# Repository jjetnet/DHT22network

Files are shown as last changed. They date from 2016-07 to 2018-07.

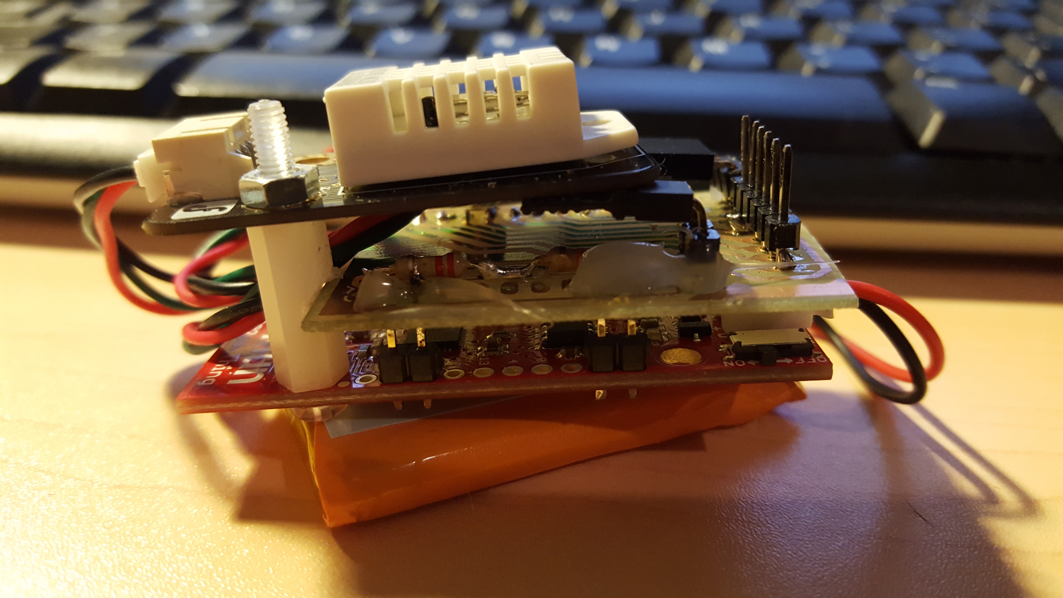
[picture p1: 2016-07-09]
example_sensor_module_assembled.jpg

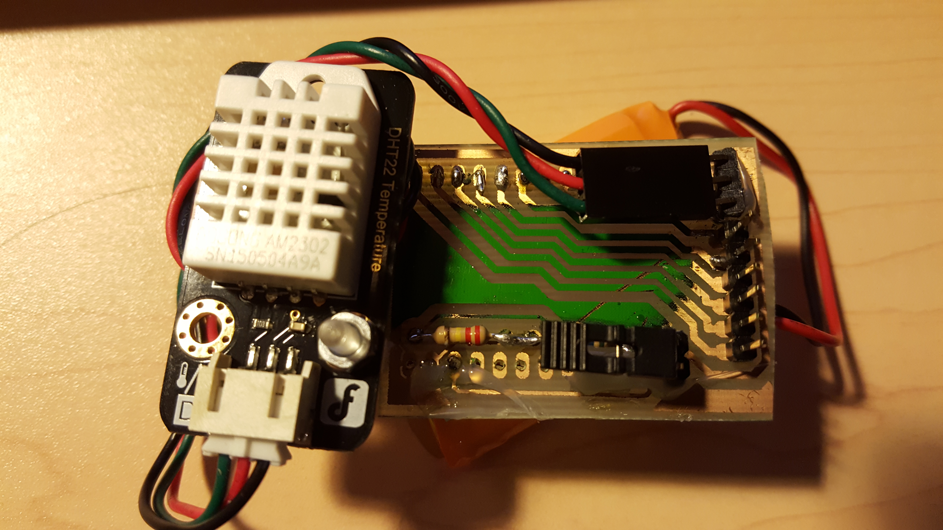
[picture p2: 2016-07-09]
sensor_module_PCB_top_view.jpg

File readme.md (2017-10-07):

# DHT22network
wifi dht22 network

Note: there are many similar, and probably better implementation of
similar concepts. My python coding in particular is far from optimal
or elegant. This implementation has mobile notifications, plots and water partial pressure
calculations which distinguishes it from others, but if you don't need
this look around for better implementations.

## Overview:

Arduino code, eagle files and python script for a wifi based array of
humidity and temperature sensors sending data back periodically to a
server. The server generates plots and tables of current data
displayed on a webpage - on the local server, and/or on a remote web
server through ftp. The sensors are meant for indoors reading, with
outside temperature read from publicly available data from the
Australian bureau of meteorology (data for australia only...).  The
number of sensors is not really limited (Although past a certain
number i'm sure bugs will emerge), and the server just adapts when a
new sensor comes online.

Each sensor can be battery operated for a number of months or even
years depending on refresh settings and battery - power consumption
between readings is minimal. The server can send notificatinos to
android and iphone phones using the free pushetta service/app (See
www.pushetta.com) when outside temperature goes above or below user
defined thresholds - useful to remember to close windows, curtains or
blinds.  Each sensor also reads its battery level, also displayed on
the webpage as battery voltage with a crude red/green color coding
depending on battery state.

For example of what the webpage looks like see
webpageexample.png. Data displayed includes temperature, relative
humidity and the water partial pressure - the latter is absolute
rather than relative, and is more informative if you want to control
the flow of humidity between two rooms or between outdoows and
indoors: if two rooms are at different temperatures but identical
relative humidity, there will still be a net flow of water vapour from
the space with the higher partial water pressure to the room with the
lower one. If you want to keep humidity down indoors in summer, this
is the quantity to watch to close/open windows, rather than the
relative humidity.

Each sensor is based on an esp8266 - specifically i used a sparkfun
esp8266 thing, which includes a convenient LiPo battery charger. Wifi
network and key, location name, and python server addess and port have
to be adjusted in the arduino code before uploading.

The server collecting data is a python script, which has to be run
with sufficient priviledges to write onto the web server's folder (eg
`/var/www/` ). All server data is defined in a separate configuration
script (tempTCPconfig.py). I run mine on a raspbery pi.

## Hardware

A minimal version can be assembled without PCB, using a ESP8266 thing the DHT22 sensor, and a jumper wire between XPD and DTR (which needs to be removed for programming). To add battery monitoring, two resistors straight onto the ESP8266 thing between Vin, Gnd and Analog in forming a ~1/5 voltage divider is enough. (220k between Vin and Analog in, 56k between gnd and Analog in) (see eagle schematic for details).

Alternatively, a PCB can be used to clean up the circuit: 

The current version of the pcb (eagle file) is awkward - components are on
the copper side, which makes for some difficult soldering for some
pins.

The two jpeg files show an example of an assembled sensor module using PCB,
outside its casing - as mentioned it is a tad awkward in this
implementation. There's some hot glue that was requried to stabilise
some of the copper wiring which had lifted off when accidentally
pushing on the module... The top view with sensor rotated shows the
two resistors that make up the voltage divider to bring the battery
voltage within the range of the ESP8266 1V ADC, as well as the jumper
that needs to be removed for programming (it connects XPD to DTR to
enable deep sleep - see [sparkfun's sleepmode tutorial](https://learn.sparkfun.com/tutorials/esp8266-thing-hookup-guide/example-sketch-goodnight-thing-sleep-mode). The
six open pins are a copy of the programming port of the esp8266 so
that the the module can still be programmed.  This particular example
uses a DHT22 module from df robotics, but a naked DHT22 can also be
used.

For the battery to last months rather than hours or days, the power LED has to be disconnected, see [sparkfun's sleepmode tutorial](https://learn.sparkfun.com/tutorials/esp8266-thing-hookup-guide/example-sketch-goodnight-thing-sleep-mode)

For this example, I used a LiPo 1000mAh LiPo battery, which is of similar size to the esp8266 thing module.

## Installation:
The python-based server requires a number of libraries,
some of which are not in the default python install for raspberry
pi (if you chose to run the server on a raspberry pi). In particular pushetta, matplotlib and a recent version of numpy
are requried, which you may have to install from source depending on
your distribution/package manager. I'm not sure which version is
required, but it runs with numpy 1.11.0, matplotlib 1.1.1rc2, pushetta
1.0.15.
Notifications require a free account with the pushetta service. For this, and how to install the pushetta python package, see [the puhsetta help page](http://pushetta.com/pushetta-docs).
Feel free to contact me (open an issue) if you have any trouble installing or running the server.

## Updates:
### 13/08/16
* increased stability: exception handling for ftp and pushetta. The python server seems very stable now.
* remover redundant, unused plot routine.

### 30/07/16
* fixed stability issues when remote ftp server or bureau of meteorology websites are not responsive.
* fixed plotting - no more error messages when insufficient data points, and limited long-term plot to last 30 days for readability

## Known issues:
* Arduino code:  If the server is down or a sensor module fails for any other reason to communicate with the server, it will keep trying continuously for ever - the battery will then run out rapidly.
* safety: ftp passwords are in clear text in the python configuration file, and  so is the wifi password in the arduino code. MAke sure to protect those files. TCP communications between sensor module and server are unencrypted.

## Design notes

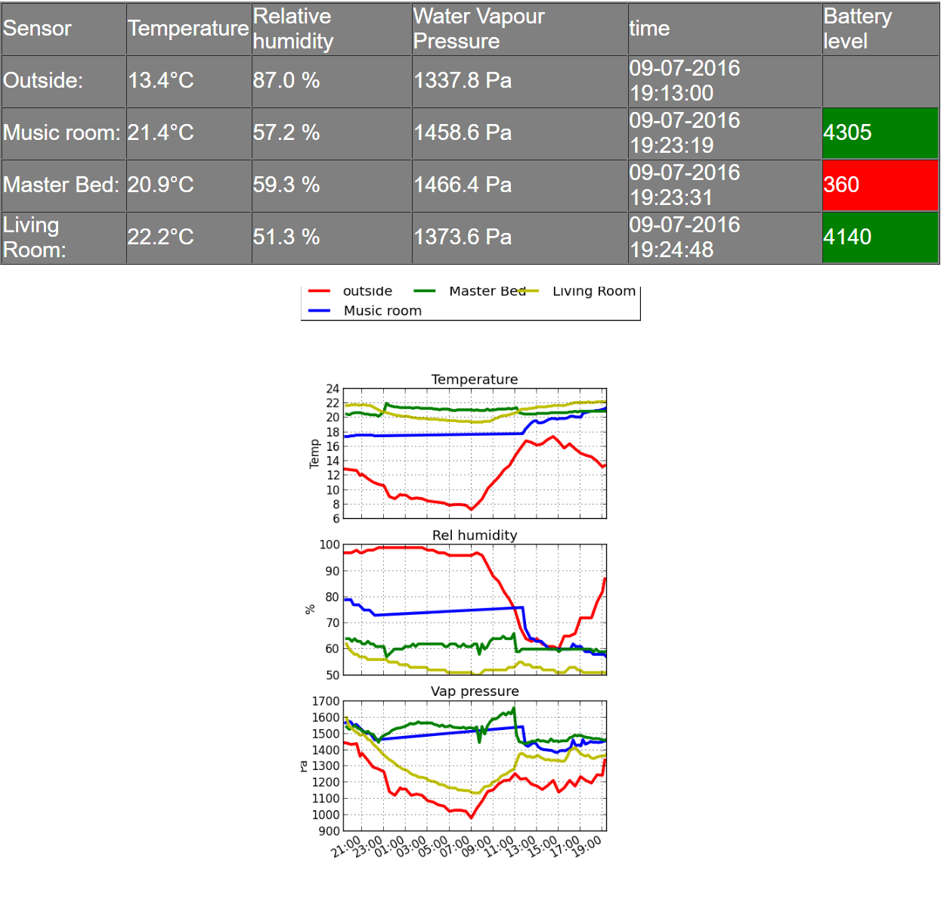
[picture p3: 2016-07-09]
webpageexample.png

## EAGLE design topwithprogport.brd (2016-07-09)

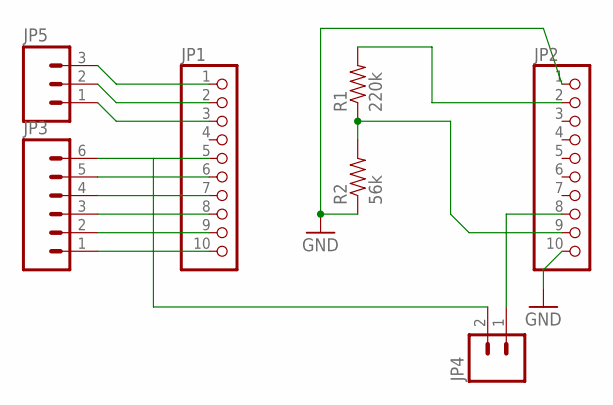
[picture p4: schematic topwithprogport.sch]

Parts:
JP1, JP2: PINHD-1X10; 1X10
JP3: M06LONGPADS; 1X06_LONGPADS
JP4: M02LOCK_LONGPADS; 1X02_LOCK_LONGPADS
JP5: M03LOCK_LONGPADS; 1X03_LOCK_LONGPADS
R1: 220k; AXIAL-0.4
R2: 56k; AXIAL-0.4

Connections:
GND: JP1.1, JP2.1, JP2.10, JP5.3, R2.P$1 (1)
unnamed: JP2.9, R1.P$1 (1), R2.P$2 (2)
unnamed: JP2.2, R1.P$2 (2)
unnamed: JP2.8, JP4.1
unnamed: JP1.5, JP3.6, JP4.2
unnamed: JP1.6, JP3.5
unnamed: JP1.7, JP3.4
unnamed: JP1.8, JP3.3
unnamed: JP1.9, JP3.2
unnamed: JP1.10, JP3.1
unnamed: JP1.2, JP5.2
unnamed: JP1.3, JP5.1

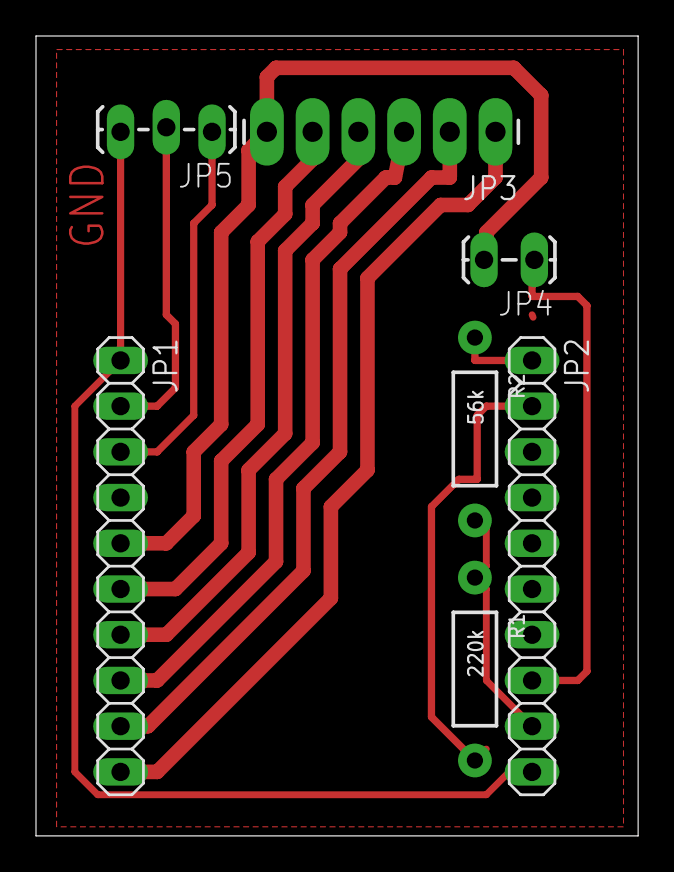
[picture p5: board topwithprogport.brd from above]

Board: 2 copper layers, 33.5 x 44.4 mm, 7 parts (0 on the bottom side), 12 nets.

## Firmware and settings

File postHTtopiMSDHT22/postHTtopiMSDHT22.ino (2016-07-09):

// Humidity and tmeperature sensor sending data to python server over wifi - based on phant post example on sparkfun
// Include the ESP8266 WiFi library. (Works a lot like the
// Arduino WiFi library.)
// REMOVE SLEEP JUMPER BEFORE UPLOADING
// apart from DHT: connect 56kOhm between ground and AD0 and 220kOhm between Vin and ground
// to measure battery voltage, mutiply AD read by 5 to get voltage
// I started from the post to phant example code of sparkfun - there are some remanents of it in here (but the code does something quite different now...)
// data is sent as a json string to the python server
// You will need to adapt WiFi definitions and server host IP/port below
#include <ESP8266WiFi.h>
#include <dht.h> //use dht

/************* uncomment this to read vdd - but useless for sparkfun thing as after regulator
extern "C" {
uint16 readvdd33(void);
}
*/

//////////////////////
// WiFi Definitions //
//////////////////////
const char WiFiSSID[] = "wifinetwork";
const char WiFiPSK[] = "yourwifipassword";
////// Each sensor needs to have a different sensor name
const char SensorID[]="Living room";

///////////////////////////////////
// Python server host definitons - adapt to your own  //
///////////////////////////////////
const char PiHost[] = "192.168.2.101";
const int PiPort = 8888;


/////////////////////
// Pin Definitions //
/////////////////////
const int LED_PIN = 5; // Thing's onboard, green LED
const int ANALOG_PIN = A0; // Analog pin (only one on ESP8266)


dht DHT;

#define DHT22_PIN 2

/////////////////
// Post Timing //
/////////////////
// Time to sleep (in minutes):
// can be updated remotely (to be implemented)
const int sleepTimeS = 15*60; //seconds (or minutes if modifying line for esp.deepsleep)

// string variables needed for posting to server
char postString[40]; // output string for client write
char charbuf[40];

void setup() 
{
  initHardware();
  connectWiFi();
  digitalWrite(LED_PIN, HIGH);
  
  while(postToPi() != 1){
    delay(200);
    }
  // deepSleep time is defined in microseconds. Multiply
  // seconds by 1e6 
  ESP.deepSleep(sleepTimeS * 1000000); //60*1000000);
}

void loop() 
{

}

void connectWiFi()
{
  byte ledStatus = LOW;

  // Set WiFi mode to station (as opposed to AP or AP_STA)
  WiFi.mode(WIFI_STA);

  // WiFI.begin([ssid], [passkey]) initiates a WiFI connection
  // to the stated [ssid], using the [passkey] as a WPA, WPA2,
  // or WEP passphrase.
  WiFi.begin(WiFiSSID, WiFiPSK);

  // Use the WiFi.status() function to check if the ESP8266
  // is connected to a WiFi network.
  while (WiFi.status() != WL_CONNECTED)
  {
    // Blink the LED
    digitalWrite(LED_PIN, ledStatus); // Write LED high/low
    ledStatus = (ledStatus == HIGH) ? LOW : HIGH;

    // Delays allow the ESP8266 to perform critical tasks
    // defined outside of the sketch. These tasks include
    // setting up, and maintaining, a WiFi connection.
    delay(200); // was 100 in original example
    // Potentially infinite loops are generally dangerous.
    // Add delays -- allowing the processor to perform other
    // tasks -- wherever possible.
  }
}

void initHardware()
{
  //Serial.begin(9600);
  pinMode(DIGITAL_PIN, INPUT_PULLUP);
  pinMode(LED_PIN, OUTPUT);
  digitalWrite(LED_PIN, LOW);
  // Don't need to set ANALOG_PIN as input, 
  // that's all it can be.
}

int postToPi()
{
  // LED turns on when we enter, it'll go off when we 
  // successfully post.
  
  digitalWrite(LED_PIN, HIGH);

  
   int chk = DHT.read22(DHT22_PIN);
   switch (chk)
  {
    case DHTLIB_OK:     
   {
       dtostrf(DHT.humidity,5,1,charbuf);
       strcpy(postString,"{\"H\": ");
       strcat(postString,charbuf );
       strcat(postString,", \"T\": ");
       dtostrf(DHT.temperature,5,1,charbuf);
       strcat(postString,charbuf );
       strcat(postString,", \"S\": \"");
       strcat(postString,SensorID);
       strcat(postString,"\", \"B\": " );  
       sprintf (charbuf, "%i", analogRead(A0)*5); // there's a /5 voltage divider
       strcat(postString,charbuf);
       strcat(postString,"}\n" );  
       break;
  }
    case DHTLIB_ERROR_CHECKSUM: 
      strcpy(postString,"{\"T\": -1,\"H\": -1, \"S\": \""); 
      strcat(postString,SensorID);
      strcat(postString,"\"}\n" );  

      break;
    case DHTLIB_ERROR_TIMEOUT: 
      strcpy(postString,"{\"T\": -2,\"H\": -2, \"S\": \""); 
      strcat(postString,SensorID);
      strcat(postString,"\"}\n" );  
      break;
    case DHTLIB_ERROR_CONNECT:
      strcpy(postString,"{\"T\": -3,\"H\": -3, \"S\": \""); 
      strcat(postString,SensorID);
      strcat(postString,"\"}\n" );  
      break;
    case DHTLIB_ERROR_ACK_L:
      strcpy(postString,"{\"T\": -4,\"H\": -4, \"S\": \""); 
      strcat(postString,SensorID);
      strcat(postString,"\"}\n" );  
        break;
    case DHTLIB_ERROR_ACK_H:
      strcpy(postString,"{\"T\": -5,\"H\": -5, \"S\": \""); 
      strcat(postString,SensorID);
      strcat(postString,"\"}\n" );  
      break;
    default: 
      strcpy(postString,"{\"T\": -6,\"H\": -6, \"S\": \""); 
      strcat(postString,SensorID);
      strcat(postString,"\"}\n" );  
      break;
  }
  // check if returns are valid, if they are NaN (not a number) then something went wrong!
    
  // Now connect to data.sparkfun.com, and post our data:
  WiFiClient client;
  
  if (!client.connect(PiHost, PiPort)) 
  {
    // If we fail to connect, return 0. double blink to show
    digitalWrite(LED_PIN,HIGH);
    delay(100);
    digitalWrite(LED_PIN,LOW);
    delay(100);
    digitalWrite(LED_PIN,HIGH);
    delay(100);
    digitalWrite(LED_PIN,LOW);
    delay(100);

    return 0;
  }
  // If we successfully connected, print our Phant post:
  client.print(postString);

  // Read all the lines of the reply from server and print them to Serial
  //while(client.available()){
    //String line = client.readStringUntil('\r');
    //Serial.print(line); // Trying to avoid using serial
  //}
  //delay(300); // so i can see LED
  // Before we exit, turn the LED off.
  digitalWrite(LED_PIN, LOW);

  return 1; // Return success
}

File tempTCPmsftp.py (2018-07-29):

# class for current climate data hteml generation/update, includines BOM data reading
# relative humidity to water vapour partial pressure conversion, and
# reading from multiple sparkfun thing wifi sensors

import matplotlib
matplotlib.use('Agg')
import requests
    
from ftplib import FTP 
import json,math
import serial
import matplotlib.pyplot as plt
import matplotlib.dates as md
import numpy as np
import gc
import socket
import threading
import sys
import matplotlib.cbook as cbook
from pushetta import Pushetta
# import network configuration etc
from tempTCPconfig import *

#import time
from time import asctime,localtime,time,sleep,strftime,strptime,mktime
import datetime
NaN=float('NaN')

dateconv = np.vectorize(datetime.datetime.fromtimestamp)
class TCPlistener:
    def __init__(self,port,errfilen):
        # initiate TCP listener on port port, log errors on file object errfilen, which must be open
        self.port=port
        self.s = socket.socket(socket.AF_INET, socket.SOCK_STREAM)
        self.s.setsockopt(socket.SOL_SOCKET, socket.SO_REUSEADDR, 1)
        self.errfilen=errfilen;
        #Bind socket to local host and port
        self.exitloop=False
        try:
            self.s.bind(('', port))
        except socket.error as msg:
            self.inflog('Bind failed. Error Code : ' + str(msg[0]) + ' Message ' + msg[1]);
            sys.exit()
            self.exitloop=True

        self.s.listen(5)
        self.TCPlistener()
        
    def _TCPlistener(self):
        # listens to TCP port and start new thread for each connection
        # call through TCPlistener to put this in non blocking thread
        while not self.exitloop:
            # print '.'
            conn, addr = self.s.accept()
            self.inflog('Connected with ' + addr[0] + ':' + str(addr[1]))
            t=threading.Thread(target=self.clientthread ,args=(conn,))
            t.start()
            t.join()

        self.s.close()
        sys.exit()


    def TCPlistener(self):
        threading.Thread(target=self._TCPlistener).start()
        
    def clientthread(self,conn):
    #infinite loop so that function do not terminate and thread do not end. probably not needed with curent exit condition
        while True:
            #Receiving from client
            
            data = conn.recv(1024)
            self.inflog('"'+data.strip()+'"')
            if(data!=''):
                try:
                    sensordata=json.loads(data)
                    self.it=sensordata["T"]
                    self.ih=sensordata["H"]
                    self.sensorID=sensordata["S"]
                    try:
                        self.battery=sensordata["B"]
                    except:
                        self.battery=-1

                    self.itimestamp=localtime(time())
                    self.gotnewdata=True
                    break
                except:
                    self.inflog('json error: "'+str(data)+'"')
                    data=False
                    break

#                conn.send('
            #reply = 'OK...' + data
            if not data: 
                break

            #conn.sendall(reply)

        #came out of loop
        conn.close()
	return 0
    
    def inflog(self,txt):
        txt=strftime('%d-%m-%Y %H:%M:%S')+': '+txt+'\n'
        self.errfilen.write(txt)
        self.errfilen.flush()
          

class climatehtmlfileTCP:
    def __init__(self,filepath,bomurl,fileradix,port,errfile,lowT,highT):
        self.filename=filepath+fileradix+'.html'
        self.bomurl=bomurl
        self.datalogfile=filepath+fileradix
        self.fileradix=fileradix
        self.filepath=filepath
        self.port=port
        self.errfile=errfile
        self.errfilen=open(errfile,'a',0) # error file in unbuffered
        self.TCPlistener=TCPlistener(port,self.errfilen)
        self.TCPlistener.gotnewdata=False
        self.sensidtable={}
        self.lastUpdate=time()-60 
        self.alertTempLow=lowT
        self.alertTempHigh=highT
        self.sentAlertHigh=False
        self.sentAlertLow=False
        self.inflog('climateHTMLfile class initiated')
        if(API_KEY):
            self.p=Pushetta(API_KEY)
            self.p.pushMessage(CHANNEL_NAME,"Service started")            
        else:
            self.p=False

    def inflog(self,txt):
        txt=strftime('%d-%m-%Y %H:%M:%S')+': '+txt+'\n'
        self.errfilen.write(txt)
        self.errfilen.flush()
            
    def waterPartialPressure(self,temperature,humidity):
        "Calculates watersaturatiopressure(temperature,humidity) temperautre (C), h (%)"
        # formula for water saturation vapor pressure from
        # http://www.vaisala.com/Vaisala%20Documents/Application%20notes/Humidity_Conversion_Formulas_B210973EN-F.pdf
        Tc = 647.096 
        Pc = 22064000
        C1 = -7.85951783
        C2 = 1.84408259
        C3 = -11.7866497
        C4 = 22.6807411
        C5 = -15.9618719
        C6 = 1.80122502
        t=1-(temperature+273.15)/Tc
        pw=humidity/100*Pc*math.exp(Tc/(temperature+273.15)*(C1*t+C2*math.pow(t,1.5)+C3*math.pow(t,3)+C4*math.pow(t,3.5)+C5*math.pow(t,4)+C6*math.pow(t,7.5)))
        #print pw
        return pw

    def getBomData(self):
        "get BOM observations"
        try:
            response=requests.get(self.bomurl)
            self.bomdata=json.loads(response.content)
            self.ot=float(self.bomdata["observations"]["data"][0]["air_temp"])
            self.oh=float(self.bomdata["observations"]["data"][0]["rel_hum"])
            self.bomdatatime=self.bomdata["observations"]["data"][0]["local_date_time"]
            bomd=self.bomdata["observations"]["data"][0]["local_date_time_full"]
            self.bomdatatimefull=strptime(bomd,"%Y%m%d%H%M%S")
            self.op=self.waterPartialPressure(self.ot,self.oh)
            self.hasbomdata=True
        except:
            self.hasbomdata=False
            self.ot=NaN
            self.op=NaN
            self.oh=NaN
            self.bomdatatime=localtime()
            self.bomdatatimefull=localtime()
            self.inflog("failed to load bom data")
				   

    def getSensorData(self):    
        #data comes from TCP reader - here we just update the vapour pressure based on existing data
        if self.TCPlistener.ih<0:
             self.hasSensorData=False
             self.inflog(asctime()+'Sensor error: '+str(self.TCPlistener.sensorID)+'returned '+str(self.TCPlistener.ih)+'\n')
        else:
            self.addSensorData(self.TCPlistener.it,self.TCPlistener.ih,self.TCPlistener.sensorID,self.TCPlistener.itimestamp, self.TCPlistener.battery)
            self.hasSensorData=True
            
    def addSensorData(self,t,h,sensid,timest,b):
        ip=self.waterPartialPressure(t,h)
        self.sensidtable[sensid]={'T': t,'H': h, 'P': ip, 'Time': timest,'B': b}
        self.adddatatologfile(sensid)
        
    def addlinetotable(self,text):
        self.filen.write("<tr>"+text+"</tr>")
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

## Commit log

2016-07-09 Initial release
    Mostly stable - see readme
    [topwithprogport.brd, topwithprogport.sch]
2016-07-09 added pictures of sensor module
2016-07-30 stability fixes
    * fixed stability issues when remote ftp server or bureau of meteorology
    websites are not responsive
    * fixed plotting - no more error messages when insufficient data points,
    and limited long-term plot to last 30 days for readability
    [tempTCPmsftp.py]
2016-08-13 increased stability - added installation instructions
    [tempTCPmsftp.py]
2017-10-07 streamlined error logging
    also changed to arduino folder structure
    [postHTtopiMSDHT22.ino, tempTCPmsftp.py]
2017-10-07 fixed 'invalid value enountered bug' when date list contains NaN
    [tempTCPmsftp.py]
2017-10-07 fixed error causing crash shortly after startup when only one data point available for day
    the server would crash after the first data is recieved if the server
    had been down for more than a day. This has now been fixed.
    Other bug fixes:
    - standard python error reporting is back
    - output files are flushed after writing to avoid delay in reportring
    - data is no longer duplicated in csv files
    - warning due to NaN is files fixed
    - fixed error mistakenly calling pushetta push when no pushetta channel
    is defined at program exit
    [tempTCPmsftp.py]
2018-07-29 changed urllib2 to requests
    BOM website was updated and did not respond to urllib2 requests without
    several additional headers - causing 403 errors in the previous version.
    Using requests library instead of urllib2 avoids this problem - and is
    easier.
    Also added checking that BOM data wasn't logged already for same time
    stamp to avoid duplication of data.
    [tempTCPmsftp.py]

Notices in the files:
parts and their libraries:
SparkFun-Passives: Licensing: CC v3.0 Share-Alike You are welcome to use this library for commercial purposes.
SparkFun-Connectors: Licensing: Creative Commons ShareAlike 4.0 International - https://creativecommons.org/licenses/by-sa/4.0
